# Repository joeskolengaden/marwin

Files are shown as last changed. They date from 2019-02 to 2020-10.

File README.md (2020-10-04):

# MARWIN
An Open Source Rapid Deployable DIY MARS Rover developed by Motify

## Primary Aim
To develop an opensource space rover by utilizing all posiible opensoure materals & resourses and also make the rover flexible  deployable for multiple purposes including research, resuce, military and defence purposes.

## Abstract

MARWIN is intended to be one of the first opensource DIY space rover projects which could be developed very easily. The rover is designed to be highly customizable with a modular design approach. MARWIN could open up the future for rapidly deployable rover solutions for exploration of other planets.

MARWIN intends to reduce the manufacturing cost and development time of rovers by implementing a quick and standardized design approach which could be customized very easily.

## Implementation Plan

* Rocker-Bogie system with RC.
* Scientific equipments ( sensor clusters).
* Power management system.
* Autonomous navigation.
* Video streaming and analysis.
* Testing and analysis.
* Modification and finalizing the design.

# Rover Actions Flowchart:



## For more details please check the WIKI page https://github.com/joeskolengaden/marwin/wiki

### Each folder in this MARWIN contains different areas of IoT projects, So this project can be splitted to different small scale projects, Enjoy MARWIN by Motify.in

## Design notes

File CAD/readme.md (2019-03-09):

This folder contains the Auto CAD files that is used for CNC cutting.

And in this file it includes the whole design of wheel of MARWIN.

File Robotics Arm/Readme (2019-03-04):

/*

NOTE: Four Servos of the Robotic Arm are connected to 4 PWM Pins of Arduino 

and these 4 servos are named a, b, c and d. 

If you want to control servo a, then type "90a/", 

where "90" is the PWM value (range is 0 - 255), 

"a" means servo a and "/" is string parse delimiter. 

Some other examples: 100a/ or 120b/ or 40c/ or 25d/

*/

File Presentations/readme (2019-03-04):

This folder contains the powerpoint presentations that we used for each reviews during the time of our project.

And each powerpoint presentation is uploaded here in the name of reviews.

Each powerpoints will have extremly minute changes in each slides so don't be much excited on each update on the powerpoints.

Final powerpoint will be uploaded on the time of our completion of project.

Enjoy the opensource DIY mars rover MARWIN by motify.in

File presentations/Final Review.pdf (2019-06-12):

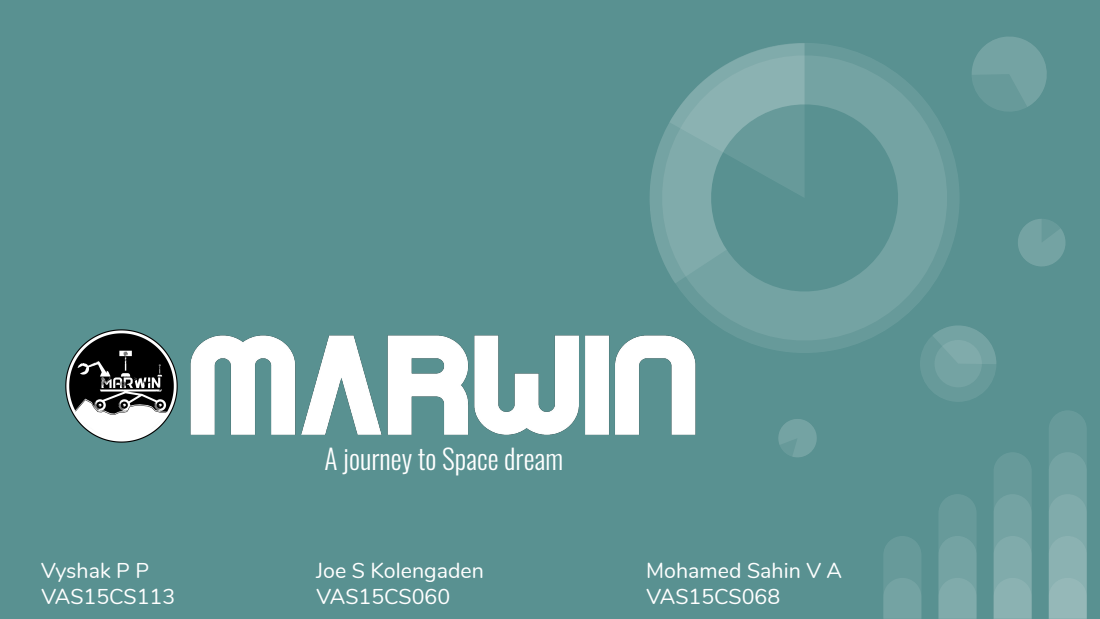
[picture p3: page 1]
Vyshak P P; Joe S Kolengaden; Mohamed Sahin V A; VAS15CS113; VAS15CS060; VAS15CS068

A journey to Space dream

# Contents

- Abstract
- Problem statement
- Methodologies
- Implementation Plan
- RoadMap
- Current progress
- Issues faced during prototyping
- Conclusion and Future scope

# Abstract

The basic aim behind the project is to address the need of open source projects in space industry. MARWIN is intended to be one of the first open source DIY space rover projects which could be developed very easily. The rover is designed to be highly customizable with a modular design approach. MARWIN could open up the future for rapidly deployable rover solutions for exploration of other planets. MARWIN intends to reduce the manufacturing cost and development time of rovers by implementing a quick and standardized design approach which could be customized very easily.

# Problem statement

To develop an open source space rover by utilizing all possible open source materials & resources and also make the rover flexible deployable for multiple purposes including research, rescue, military and defence purposes.

# Methodologies

- Architecture of MARWIN
- Rocker-Bogie Mechanism
- Sensor cluster
- Obstacle avoidance
- Obstacle detection
- Obstacle searching
- Rerouting
- Object detection
- WebApp

# Architecture of MARWIN

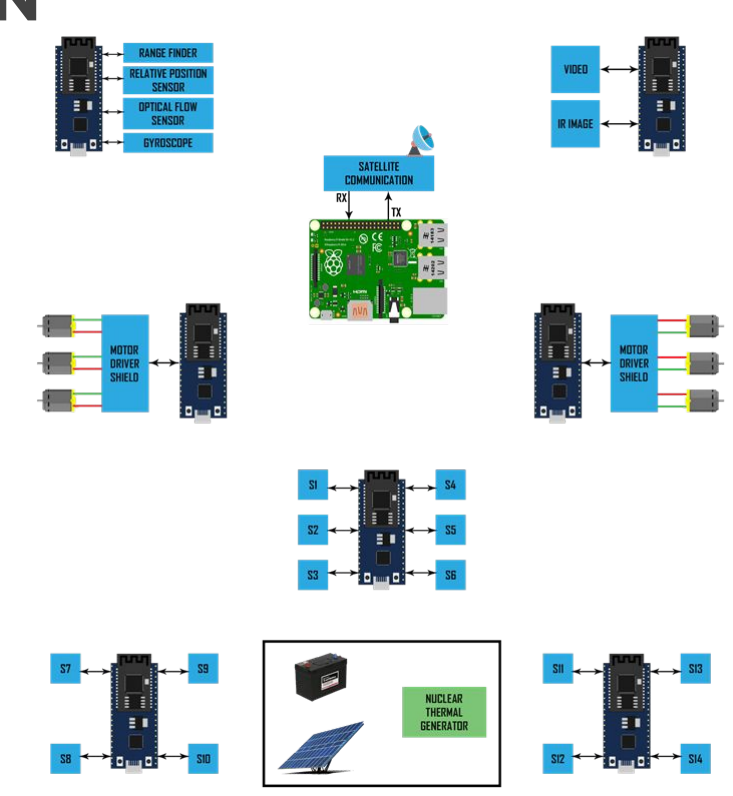
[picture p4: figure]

Modular designs are used in this architecture.

# Rocker-Bogie mechanism

- The ”rocker” part of the term comes from the rocking aspect of the larger, forward leg on each side of the suspension system. These rockers are connected to each other and the vehicle chassis through a differential.
- The ”bogie” part of the term refers to the smaller, rearward leg that pivots to the rocker in the middle and which has a drive wheel at each end.
- The rocker-bogie design has no springs or stub axles for each wheel, allowing the rover to climb over obstacles (such as rocks) that are up to twice the wheel’s diameter in size while keeping all six wheels on the ground.

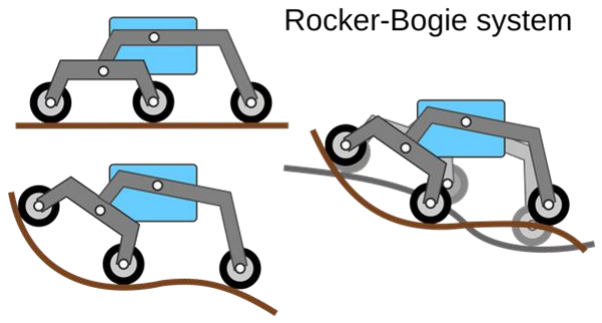
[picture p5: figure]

# Gas Sensor Cluster

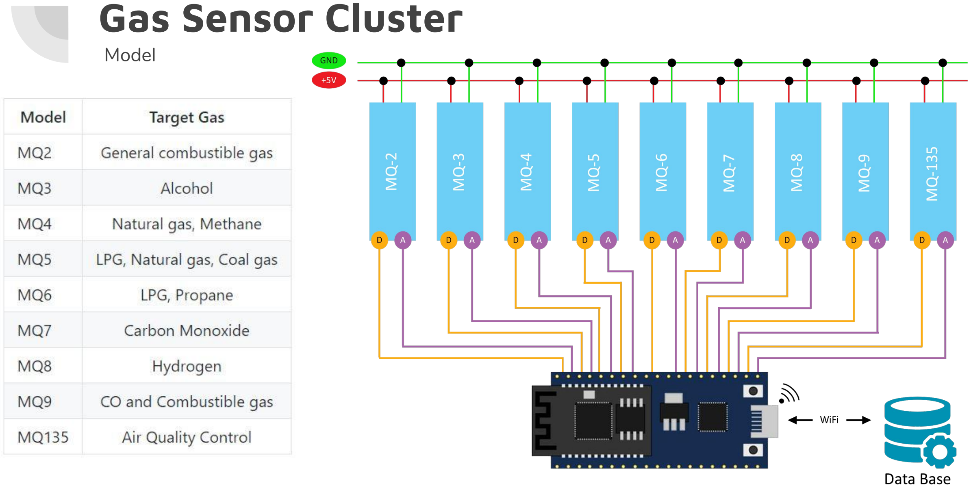
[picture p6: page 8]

Model

# Obstacle avoidance

Obstacle avoidance contains basic 3 algorithms namely,

- Obstacle detection
- Obstacle searching
- Rerouting

# Obstacle detection

Algorithm & FlowChart

1. Start

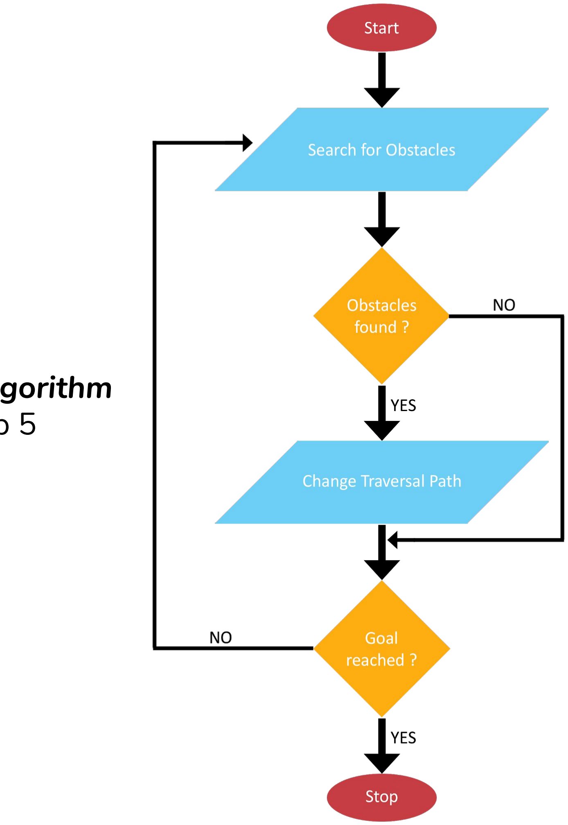
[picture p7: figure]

2. Search for obstacle using Obstacle Searching Algorithm
3. If found then change traversal path and goto step 5
4. Else goto step 5
5. Check whether goal is reached ?
6. If yes then goto step 8
7. Else goto step 2
8. Stop

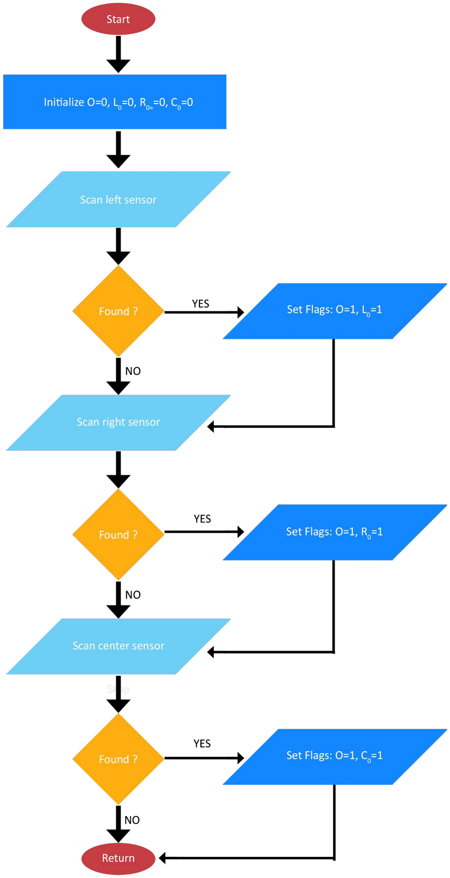
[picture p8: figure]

# Obstacle Searching

Algorithm & FlowChart

1. Start
2. Initialize flag variables O=0, Lo=0, Ro=0, Co=0
3. Scan Left sensor for obstacles.
4. If found then set flags O=1, Lo=1 and goto step 6
5. Else goto step 6
6. Scan Right sensor for obstacles.
7. If found then set flags O=1, Ro=1 and goto step 9
8. Else goto step 9
9. Scan Center sensor for obstacles.
10. If found then set flags O=1, Co=1 and goto step 12
11. Else goto step 12
12. Return to Obstacle Detection Algorithm with sensor values.

# Rerouting

Algorithm & FlowChart
1. Start

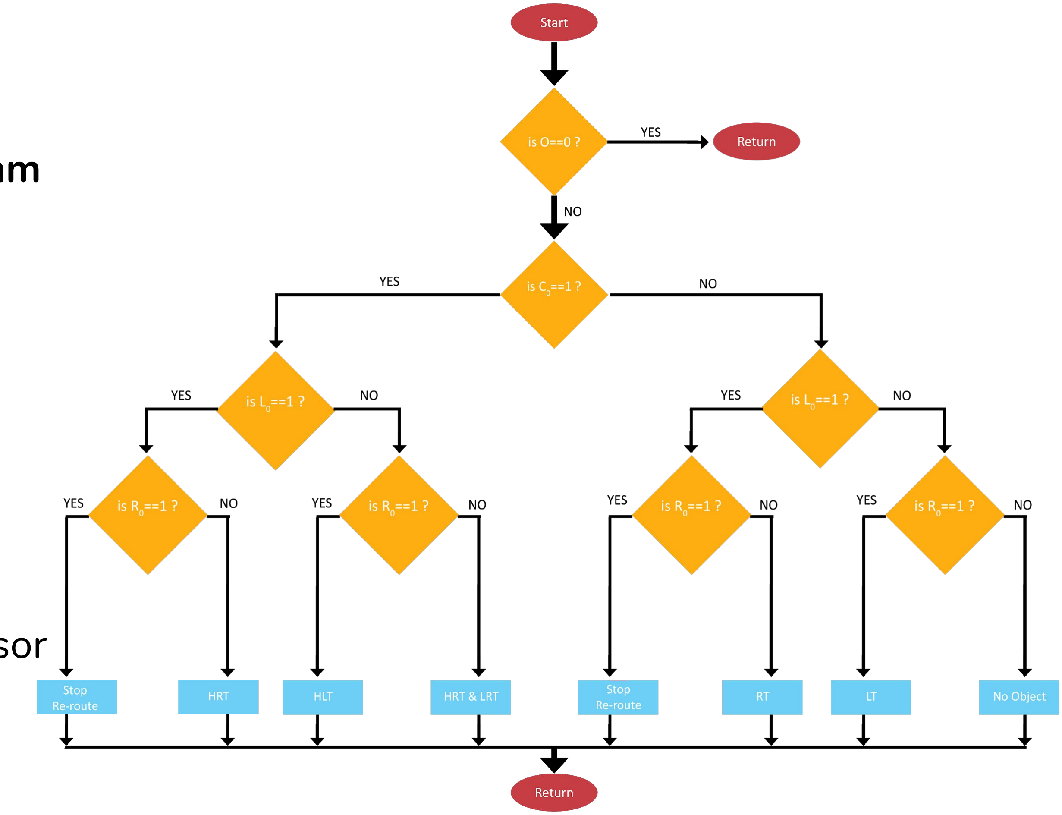
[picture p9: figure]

2. If O=0 then Return to Obstacle Detection Algorithm
3. Else do steps a to h
a. If Lo=1 & Ro=1 & Co=1 then stop & reroute
b. If Lo=1 & Ro=0 & Co=1 then HRT
c. If Lo=1 & Ro=0 & Co=0 then RT
d. If Lo=0 & Ro=1 & Co=1 then HLT
e. If Lo=0 & Ro=1 & Co=0 then LT
f. If Lo=0 & Ro=0 & Co=1 then HRT/HLT
g. If Lo=1 & Ro=1 & Co=0 then stop & reroute
h. If Lo=0 & Ro=0 & Co=0 then No Obstacles
4. Return to Obstacle Detection Algorithm with sensor values.

# Rerouting

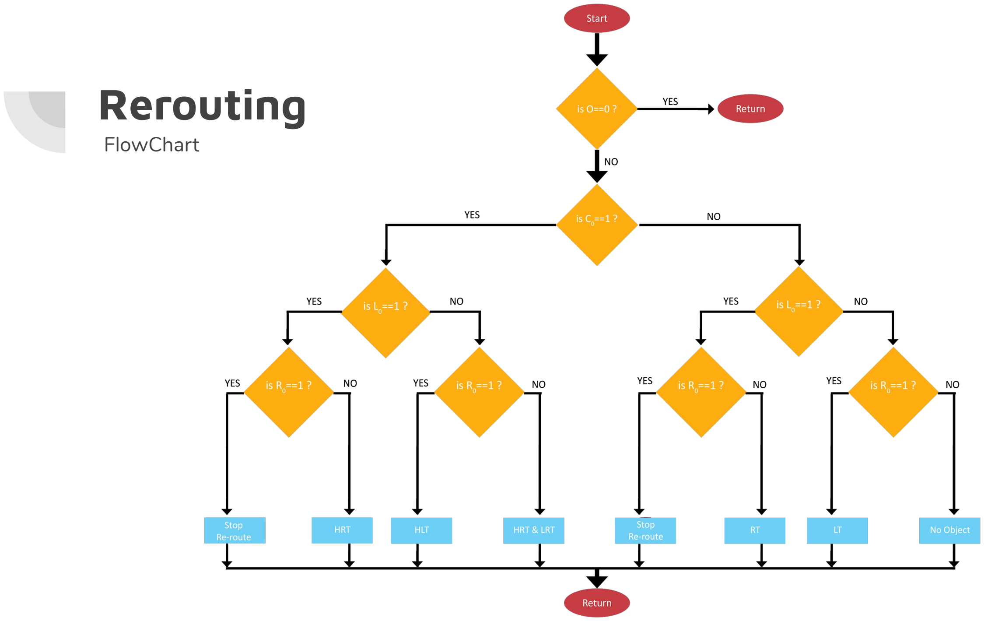
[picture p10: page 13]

FlowChart

# Object detection

Prior detection systems repurpose classifiers or localizers to perform detection. They applythemodeltoanimageatmultiplelocationsandscales. Highscoringregionsofthe image are considered detections.

Here we used TensorFlow for object detection.

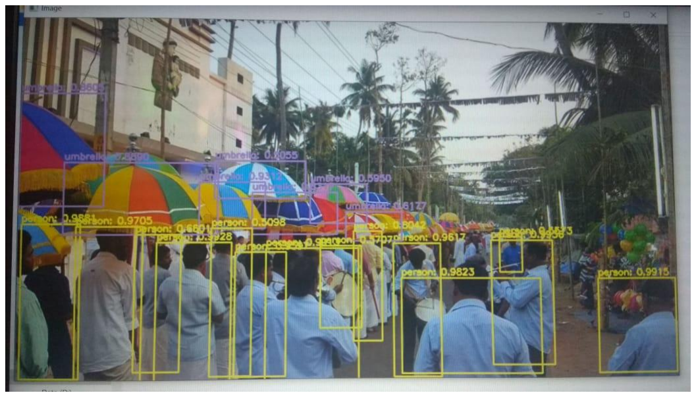
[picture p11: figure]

# Working

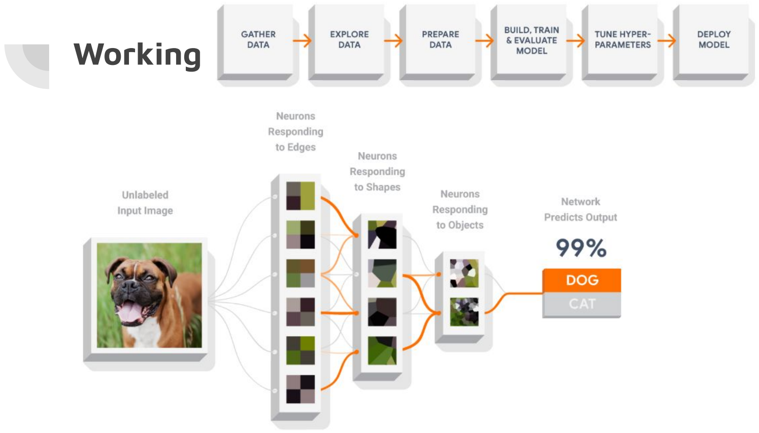
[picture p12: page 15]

# WebApp

A web application is a computer program that utilizes web browsers and web technology to perform tasks over the Internet.

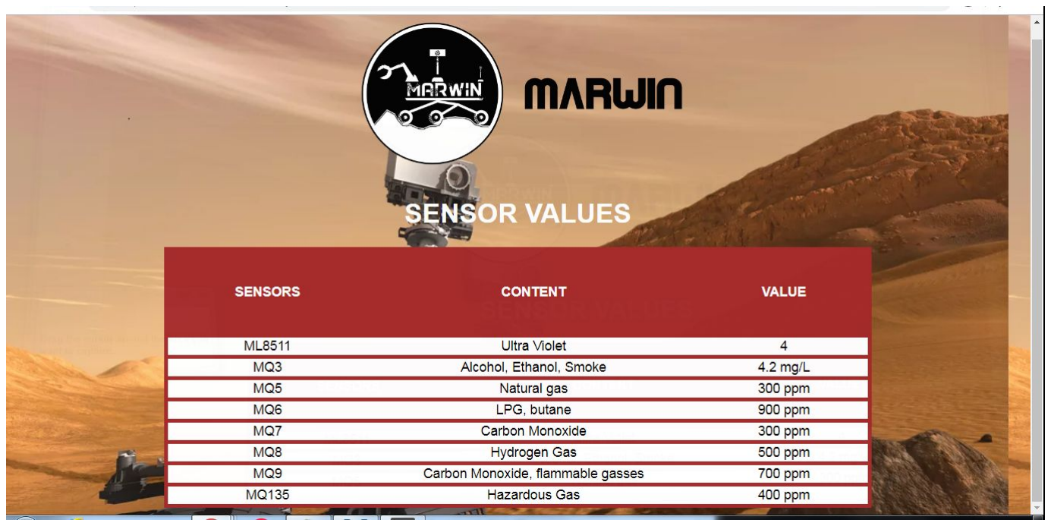
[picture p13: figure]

Our web app is created using:

- Flask : Python Based mini-Web Framework
- MongoDB : Database Server
- Pymongo : Database Connector
- HTML : For webpage

# Implementation Plan

- Rocker-Bogie system.
- Scientific equipments (sensor clusters).
- Power management system.
- Autonomous navigation.
- Video streaming and analysis.
- Testing and analysis.
- Modification and finalizing the design

# RoadMap

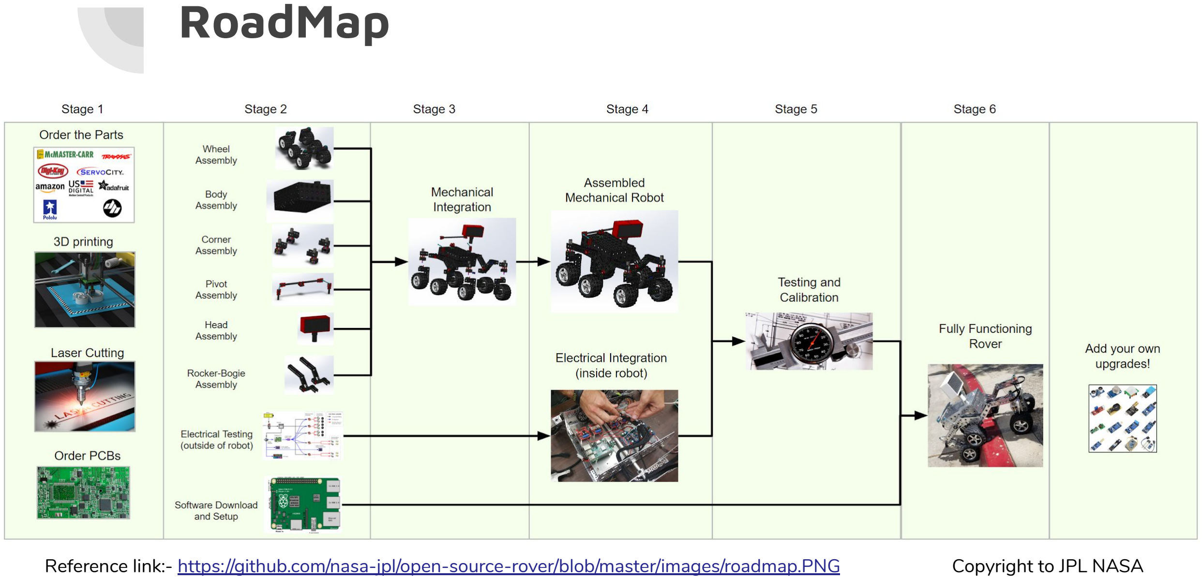
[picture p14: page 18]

Reference link:- https://github.com/nasa-jpl/open-source-rover/blob/master/images/roadmap.PNG | Copyright to JPL NASA

# Current Progress

- | Rocker-Bogie Mechanism | Designed
- | Object Detection | On developing
- | Gas Sensor Cluster | Developing cluster
- | Wheel Assembly | Implemented
- | WebApp | On developing
- | Navigation System | On developing

# Current Progress

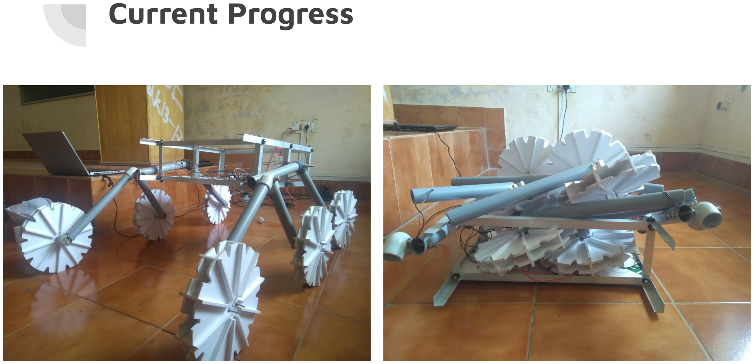
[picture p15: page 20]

# Current Progress

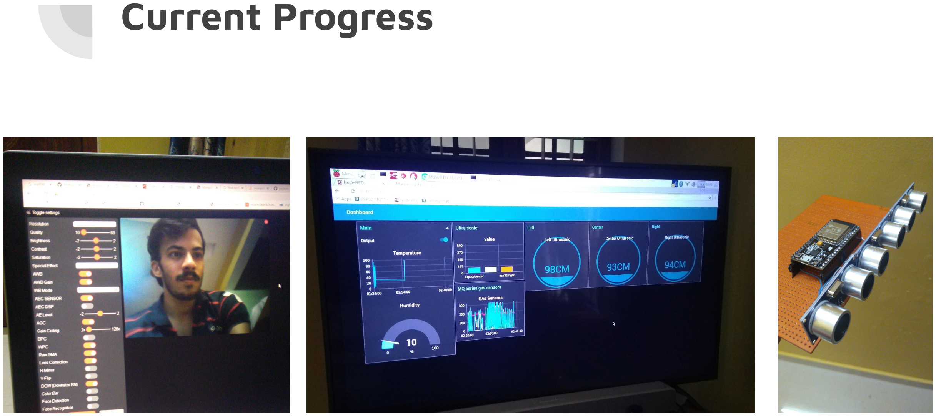
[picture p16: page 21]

# Issues Faced

- Rocker-Bogie Mechanism
- Wheel Assembly
- Sensor Clustering
- Response Time
- LIVE Object Recognition
- Robotic Arm
- Power Source
- Cost

# Conclusion and Future scope

As a team we achieved far more in a short timespan. The journey through the developing and integrating part of this project was a great one. In the present situation there are a high amount disasters happening unexpectedly also different kinds of situations are rising where the human kinds are not reachable. So we are expecting our space rover based marwin could also implement in such situations and can obtain a positive result. In future we will be able to implement the present prototype on the basis of the needs. That can be based on the situations. By improving we can make this rover more user friendly by also including machine learning concept to it. This makes the rover to learn the ongoing datas and can act as a highly AI based robot which will be completely autonomous and the human efforts decreases.

# Note

Choose the right materials and good quality electronics for making electro-mechanical projects

# GITHub

Open sourced every bit of code via Github.com

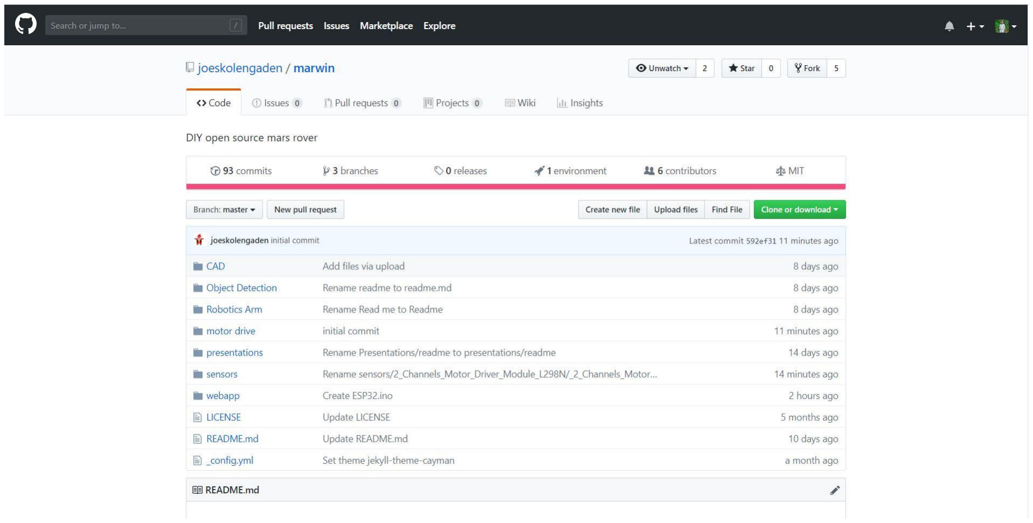
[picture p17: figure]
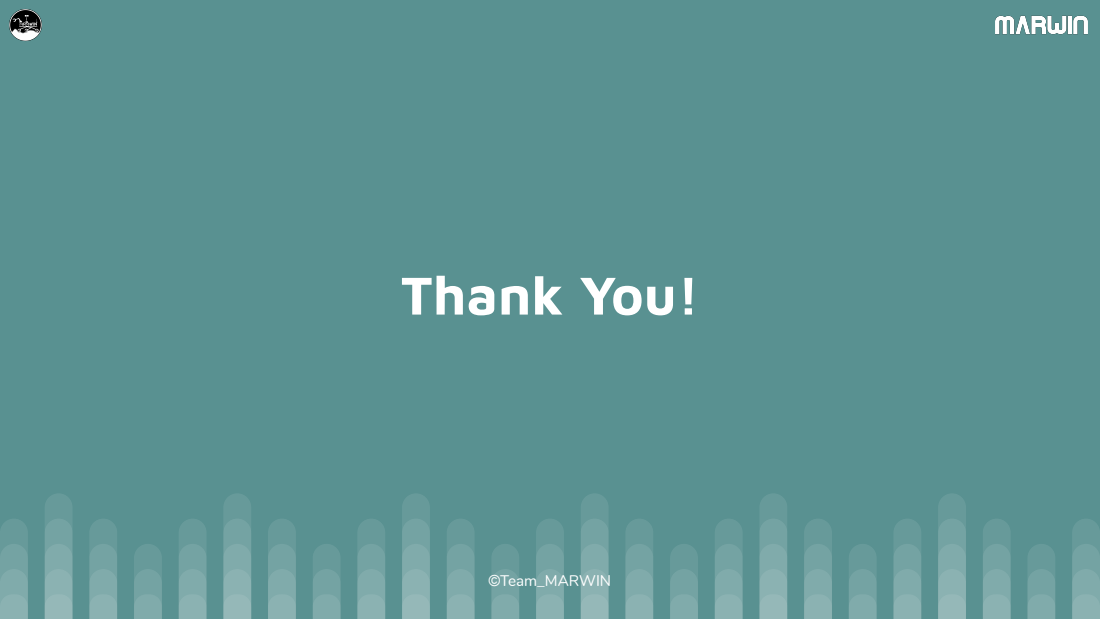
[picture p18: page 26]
Thank You!; ©Team_MARWIN

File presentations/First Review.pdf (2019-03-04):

## An Open Source Rapid Deployable DIY MARS Rover

# MARWIN

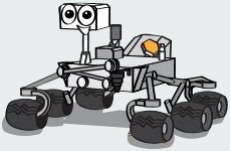
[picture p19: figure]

Team Members

Vyshak P P (VAS15CS113)

Mohamed Sahin V A (VAS15CS068)

Joe S Kolengaden (VAS15CS060)

Group A2

# Contents

## - Abstract - Problem Statement - Design - Implementation Plan

# Introduction

- Ever growing demand and developments in space exploration industry have inspired us to create MARWIN.
- Rapid industrialization and entry of private firms in space industry have opened up new possibilities for startups.

# Abstract: project background

- The basic aim behind the project is to address the need of open source projects in space industry.
- The MARWIN rover is designed to be modular and customizable according to various explorational needs.
- The basic use of MARWIN will be to avail rapid deployable rover solutions in human exploration of other planets.

# Problem statement:

- The working of space rover cannot be exhibited to the public directly and it is because of high maintenance costs.
- There is a lack of open-source projects that support space exploration and related technology.
- There is no available prototype or even design for rapid deployable modular rovers.

# Design

- The design principle of MARWIN is logically divided into 3*3*3 like Rubik’s Cube design approach.
- We use Rocker Bogie mechanism for traversing through rough terrain.
- We provide any of the scientific equipment in this prototype.
- Atmospheric content Sensor : Which enables us to detect the presence of different types of Gases.
- Life detecting robotic system : Which detects the presence of biological life form.

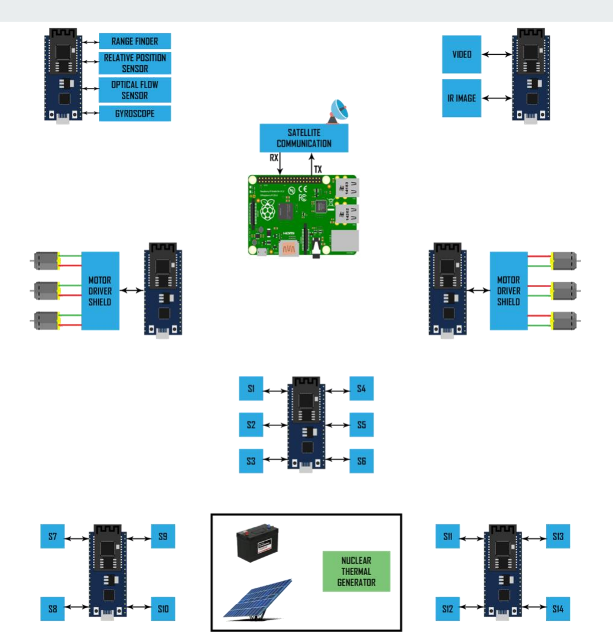
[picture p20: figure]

# Architecture

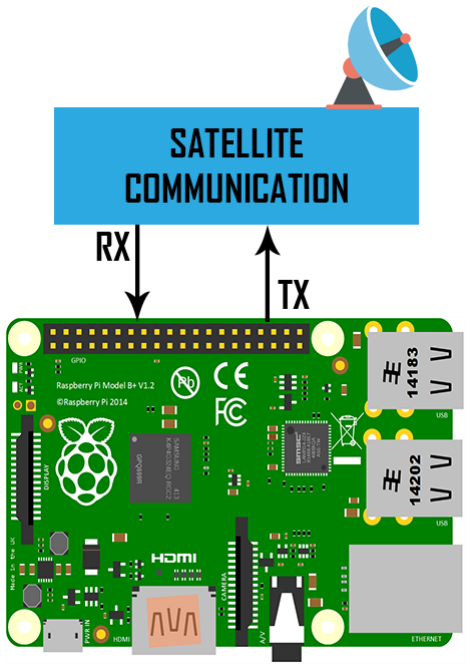
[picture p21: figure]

# Raspberry Pi 3 B+

- It acts as the brain (Motherboard).
- Buffers all data in the internal server (Database).

# Live Analysis

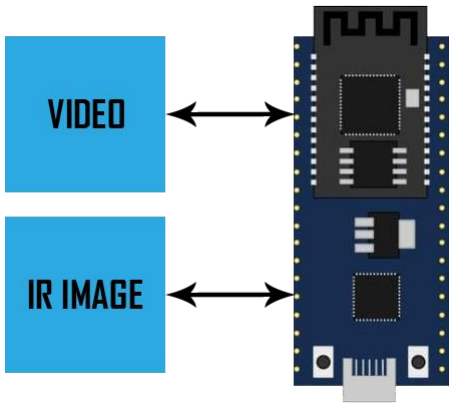
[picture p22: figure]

# Navigation Block

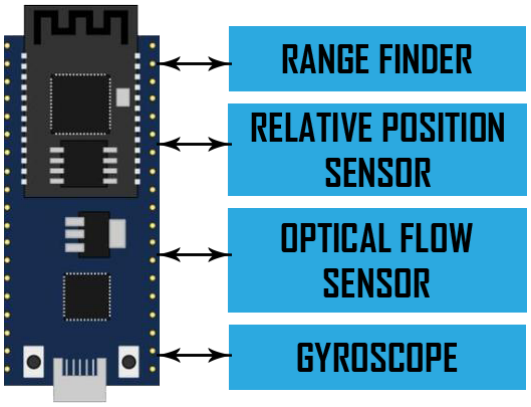
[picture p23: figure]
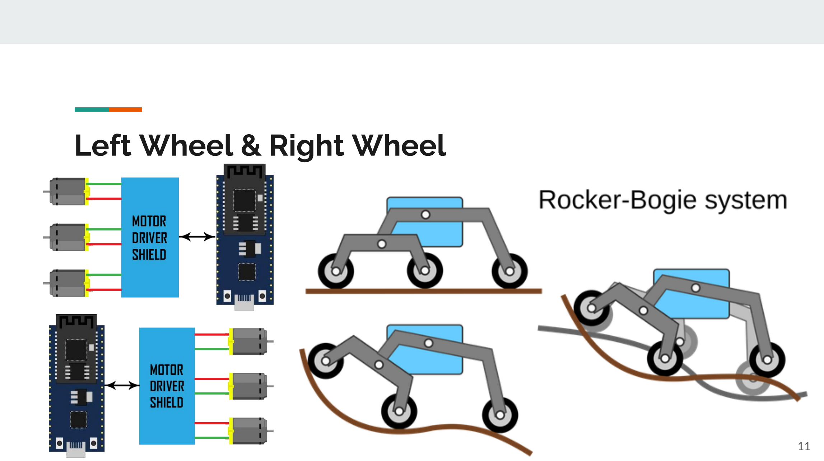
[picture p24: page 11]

# Left Wheel & Right Wheel

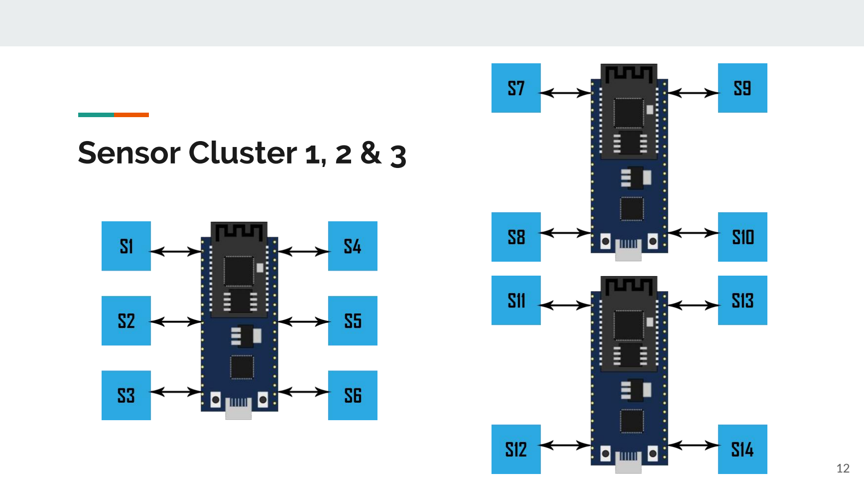
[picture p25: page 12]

# Sensor Cluster 1, 2 & 3

# Power management block

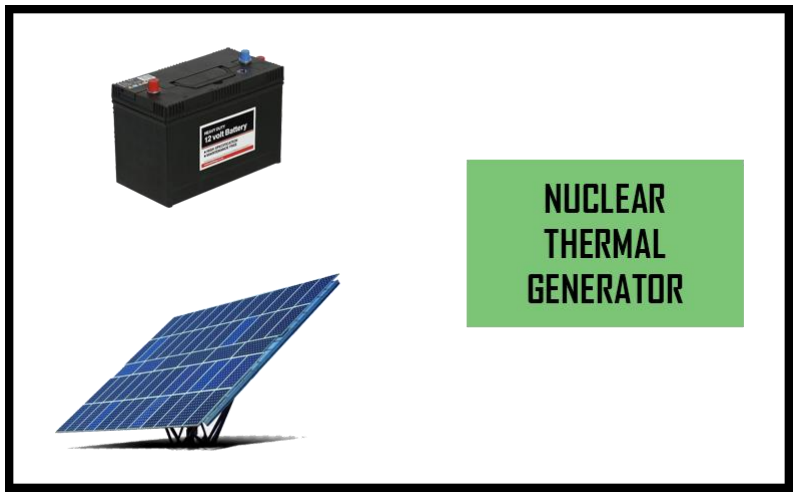
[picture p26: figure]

# Implementation Plan

1. Rocker-Bogie system with RC .
2. Scientific equipments ( sensor clusters).
3. Power management system.
4. Autonomous navigation.
5. Video streaming and analysis.
6. Testing and analysis.
7. Modification and finalizing the design.

Note: All the project work will be made open source via GitHub.


# Goal Based Navigation


# Rover Actions Flowchart


# Why ESP32 ?

# ESP32 dual core


- Each core can do different task independently.
- Sync can be achieved via Mutually Exclusive Semaphores.
- The 32bit dual core clocked at 180Mhz can outperform AtMEga328p( Arduino UNO R3) by

# Sensor list

- MQ-2 - Methane, Butane, LPG, smoke
- MQ-3 - Alcohol, Ethanol, smoke
- MQ-4 - Methane, CNG Gas
- MQ-5 - Natural gas, LPG
- MQ-6 - LPG, butane gas
- MQ-7 - Carbon Monoxide
- MQ-8 - Hydrogen Gas
- MQ-9 - Carbon Monoxide, flammable gasses
- MLX90614 - IR temperature sensor
- MAG3110 - Magnetometer
- | ITG 3200 | - Gyroscope
- ADXL 345 - Accelorometer
- | TSL 102 | - Luminosity sensor
- | ML8511 | - UV detector
- | BMP180 | - Barometric Pressure/altitude sensor
- MMA84551 - Inclination sensor

# Literature survey

- Terrain feature extraction and assessment.

## - Terrain-Based Navigation - Obstacle-Avoidance Navigation - Goal-Based Navigation - Behavior Integration

Paper: An Intelligent Terrain-Based Navigation System for Planetary Rovers

# Literature survey (cont….)

- Wheel supporting system.

## - Wheel defect detection

- Wavelet-SVM
- Deep Learning

Paper: Wheel defect detection using machine learning.

# Literature survey (cont….)

- Prototype for searching signs of life in mars.
- Laser and reflectometer tech to detect traces of methane.
- Surveying and localization of data.

Paper: Robot System to Search for Signs of Life on Mars

Applications…..

Highly modified versions of the rover can be used in fields such as

1. Defence .
2. Rescue operations.
3. Disaster management.
4. Remote sensing.
5. Agriculture.
6. R&D.

And more...

# Thank you !!


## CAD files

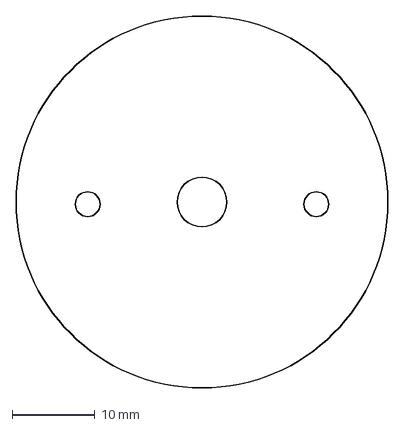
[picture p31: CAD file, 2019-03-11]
CAD/Wheel Assembly/CNC/filler.dxf
45.0 x 45.0 mm

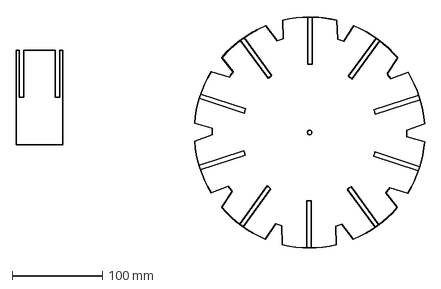
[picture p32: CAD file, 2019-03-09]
CAD/Wheel Assembly/CNC/wheel.dxf
452.9 x 258.4 mm

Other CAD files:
CAD/Wheel Assembly/CNC/filler.dwg
CAD/Wheel Assembly/CNC/wheel.dwg

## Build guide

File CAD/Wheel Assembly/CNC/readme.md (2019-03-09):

This folder contains the Auto CAD files that is used for CNC cutting.

And in this file it includes the whole design of wheel of MARWIN.

Wheel Diameter = 256 mm

Center Hole = 6 mm

Slits = 5 mm

No. of spokes = 10

Inner Clamp diameter = 51.2 mm

Inner Clamp Center hole = 6 mm

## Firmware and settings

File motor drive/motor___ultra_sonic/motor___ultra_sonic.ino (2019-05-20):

#include <WiFi.h>
#include <PubSubClient.h>
#include <Wire.h>

/*
#include "BluetoothSerial.h"

#if !defined(CONFIG_BT_ENABLED) || !defined(CONFIG_BLUEDROID_ENABLED)
#error Bluetooth is not enabled! Please run `make menuconfig` to and enable it
#endif

BluetoothSerial SerialBT;
*/

// Replace the next variables with your SSID/Password combination
 char* ssid ="motify_one";
 char* password ="trigon2016";

// Add your MQTT Broker IP address, example:
//const char* mqtt_server = "192.168.1.144";
const char* mqtt_server = "192.168.43.236";

WiFiClient espClient;
PubSubClient client(espClient);
long lastMsg = 0;
char msg[50];
int value = 0;

float left = 0;
float center = 0;
float right = 0;


int trigPin1=2;
int echoPin1=4;

int trigPin2=16;
int echoPin2=17;

int trigPin3=5;
int echoPin3=18;




//L293D
//Motor L1
const int motorPin1  = 27;  // Pin 14 of L293
const int motorPin2  = 26;  // Pin 10 of L293
int enable1Pin = 14;

//Motor R1
const int motorPin3  = 32; // Pin  7 of L293
const int motorPin4  = 33;  // Pin  2 of L293
int enable2Pin = 25;

// Setting PWM properties
const int freq = 30000;
const int pwmChannel = 0;
const int resolution = 8;
int dutyCycle = 250;





void setup() {
  Serial.begin(115200);
  
//  SerialBT.begin("ESP32test"); //Bluetooth device name
//  Serial.println("The device started, now you can pair it with bluetooth!");
     
     
     setup_wifi();
  client.setServer(mqtt_server, 1883);
  client.setCallback(callback);


  pinMode(trigPin1, OUTPUT);
  pinMode(echoPin1, INPUT);
   pinMode(trigPin2, OUTPUT);
  pinMode(echoPin2, INPUT);
   pinMode(trigPin3, OUTPUT);
  pinMode(echoPin3, INPUT);
   
    //Set pins as outputs
    pinMode(motorPin1, OUTPUT);
    pinMode(motorPin2, OUTPUT);
    pinMode(motorPin3, OUTPUT);
    pinMode(motorPin4, OUTPUT);
    
    pinMode(enable1Pin, OUTPUT);
    pinMode(enable2Pin, OUTPUT);

    // configure LED PWM functionalitites
  ledcSetup(pwmChannel, freq, resolution);
  
  // attach the channel to the GPIO to be controlled
  ledcAttachPin(enable1Pin, pwmChannel);
  ledcAttachPin(enable2Pin, pwmChannel);


}






void setup_wifi() {
  delay(10);
  // We start by connecting to a WiFi network
  Serial.println();
  Serial.print("Connecting to ");
  Serial.println(ssid);

  WiFi.begin(ssid, password);

  while (WiFi.status() != WL_CONNECTED) {
    delay(500);
    Serial.print(".");
  }

  Serial.println("");
  Serial.println("WiFi connected");
  Serial.println("IP address: ");
  Serial.println(WiFi.localIP());
}


void callback(char* topic, byte* message, unsigned int length) {
  Serial.print("Message arrived on topic: ");
  Serial.print(topic);
  Serial.print(". Message: ");
  String messageTemp;
  
  for (int i = 0; i < length; i++) {
    Serial.print((char)message[i]);
    messageTemp += (char)message[i];
  }
  Serial.println();

  // Feel free to add more if statements to control more GPIOs with MQTT

  // If a message is received on the topic esp32/output, you check if the message is either "on" or "off". 
  // Changes the output state according to the message
  if (String(topic) == "esp32/output") {
    Serial.print("Changing output to ");
    if(messageTemp == "on"){
      Serial.println("on");
      //digitalWrite(ledPin, HIGH);
    }
    else if(messageTemp == "off"){
      Serial.println("off");
      //digitalWrite(ledPin, LOW);
    }
  }
}

void reconnect() {
  // Loop until we're reconnected
  while (!client.connected()) {
    Serial.print("Attempting MQTT connection...");
    // Attempt to connect
    if (client.connect("ESP8266Client")) {
      Serial.println("connected");
      // Subscribe
      client.subscribe("esp32/output");
    } else {
      Serial.print("failed, rc=");
      Serial.print(client.state());
      Serial.println(" try again in 5 seconds");
      // Wait 5 seconds before retrying
      delay(5000);
    }
  }
}





void loop() {


 if (!client.connected()) {
    reconnect();
  }
  client.loop();

  
   long now = millis();
  if (now - lastMsg > 5000) {
    lastMsg = now;
    
  
  long duration1, distance1;
  digitalWrite(trigPin1, LOW);  // Added this line
  delayMicroseconds(2); // Added this line
  digitalWrite(trigPin1, HIGH);
  delayMicroseconds(10); // Added this line
  digitalWrite(trigPin1, LOW);
  duration1 = pulseIn(echoPin1, HIGH);
  distance1 = (duration1/2) / 29.1;
  
  
   if (distance1 >= 500 || distance1 <= 0){
    Serial.println("Out of range");
    right=distance1;
  }
  else {
    Serial.print ( "Sensor1  ");
    Serial.print ( distance1);
    Serial.println("cm");
    right=distance1;
    
  }
 //delay(200);
  
long duration2, distance2;
  digitalWrite(trigPin2, LOW);  // Added this line
  delayMicroseconds(2); // Added this line
  digitalWrite(trigPin2, HIGH);
  delayMicroseconds(10); // Added this line
  digitalWrite(trigPin2, LOW);
  duration2 = pulseIn(echoPin2, HIGH);
  distance2= (duration2/2) / 29.1;
  
  
   if (distance2 >= 500 || distance2 <= 0){
    Serial.println("Out of range");
    center=distance2;
  }
  else {
    Serial.print("Sensor2  ");
    Serial.print(distance2);
    Serial.println("cm");
    center=distance2;
    
  }
  //delay(200);
  
  long duration3, distance3;
  digitalWrite(trigPin3, LOW);  // Added this line
  delayMicroseconds(2); // Added this line
  digitalWrite(trigPin3, HIGH);
  delayMicroseconds(10); // Added this line
  digitalWrite(trigPin3, LOW);
  duration3 = pulseIn(echoPin3, HIGH);
  distance3= (duration3/2) / 29.1;

   if (distance3 >= 500 || distance3 <= 0){
    Serial.println("Out of range");
    left=distance3;
  }
  else {
    Serial.print("Sensor3  ");
    Serial.print(distance3);
    Serial.println("cm");
    left=distance3;
    
  }
  //delay(200);


                                                           //MOTOR DEIVER 
   if((right>75)&&(center>75)&&(left>75))
   {
   
    //This code will turn Motor forwards
    Serial.println("Going froward");
    
    digitalWrite(motorPin1, HIGH);
    digitalWrite(motorPin2, LOW);
    digitalWrite(motorPin3, LOW);
    digitalWrite(motorPin4, HIGH);
    }
    
    else if((right<25)&(center<25)&(left>75)){
    //this code will turn rover right
    Serial.println("Turning right");

    digitalWrite(motorPin1, LOW);
    digitalWrite(motorPin2, HIGH);
    digitalWrite(motorPin3, LOW);
    digitalWrite(motorPin4, HIGH);
    //ledcWrite(pwmChannel, dutyCycle);
    //ledcWrite(pwmChannel, dutyCycle);
   }

       else if((right>75)&(center<25)&(left<25)){
    //this code will turn rover left
    Serial.println("Turning left");

    digitalWrite(motorPin1, HIGH);
    digitalWrite(motorPin2, LOW);
    digitalWrite(motorPin3, HIGH);
    digitalWrite(motorPin4, LOW);
    //ledcWrite(pwmChannel, dutyCycle);
    //ledcWrite(pwmChannel, dutyCycle);
   }
     else if((right<25)&(center<25)&(left<25)){
    //this code will turn rover backwards
    Serial.println("Going reverse");

    digitalWrite(motorPin1, LOW);
    digitalWrite(motorPin2, HIGH);
    digitalWrite(motorPin3, HIGH);
    digitalWrite(motorPin4, LOW);
    //ledcWrite(pwmChannel, dutyCycle);
    //ledcWrite(pwmChannel, dutyCycle);
   }
   
   else if((right<75)||(center<75)||(left<75))
   {
    //this code will stop the rover 
    Serial.println("Stop");
    digitalWrite(motorPin1, LOW);
    digitalWrite(motorPin2, LOW);
    digitalWrite(motorPin3, LOW);
    digitalWrite(motorPin4, LOW);
    }

    ledcWrite(pwmChannel, dutyCycle);

    
  
  char leftString[8];
  char centerString[8];
  char rightString[8];

  dtostrf(left, 1, 2, leftString);
  dtostrf(center, 1, 2, centerString);
  dtostrf(right, 1, 2, rightString);
  
  client.publish("esp32_1/left", leftString);
  client.publish("esp32_1/center", centerString);
  client.publish("esp32_1/right", rightString);
  

  

}
}

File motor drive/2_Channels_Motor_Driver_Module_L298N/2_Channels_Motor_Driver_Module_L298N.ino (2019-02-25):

/************************************************
Editor   : MYBOTIC www.mybotic.com.my
Date     : 29 Aug 2014
Project  : 2 Channels Motor Driver Module
*************************************************/

//define motor 1 related pins
#define IN1 9
#define IN2 8
#define ENA 10

//define motor 2 related pins
#define IN3 7
#define IN4 6
#define ENB 5

void setup()
{ 
  //set output for motor 1 related pins
  pinMode(IN1, OUTPUT);
  pinMode(IN2, OUTPUT);
  pinMode(ENA, OUTPUT);
  
  //set output for motor 2 related pins
  pinMode(IN3, OUTPUT);
  pinMode(IN4, OUTPUT);
  pinMode(ENB, OUTPUT);
  
  //set motor 1 run in clockwise
  digitalWrite(IN1, HIGH);
  digitalWrite(IN2, LOW);
  
  //set motor 2 run in anticlockwise
  digitalWrite(IN3, HIGH);
  digitalWrite(IN4, LOW);
}

void loop()
{
  int PWM_Value = 0; //PWM value for motor 1 and 2
  
  //Motor 1 and Motor 2 run with gradually increasing speed until Max
  for(PWM_Value = 0; PWM_Value<=255; PWM_Value+=5)
  {
    analogWrite(ENA, PWM_Value); //set PWM to Motor 1
    analogWrite(ENB, PWM_Value); //set PWM to Motor 2
    delay(100);
  }
  
  //Motor 1 and Motor 2 run with gradually descreasing speed until Stop
  for(PWM_Value = 255; PWM_Value>=0; PWM_Value-=5)
  {
    analogWrite(ENA, PWM_Value); //set PWM to Motor 1
    analogWrite(ENB, PWM_Value); //set PWM to Motor 2
    delay(100);
  }
}

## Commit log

2019-02-16 MQ Series Gas Sensors
    initial test codes
2019-02-22 Rename mq series/mq_2/mq_2.ino to sensors/mq series/mq_2/mq_2.ino
2019-02-22 Rename mq series/mq_3/mq_3.ino to sensors/mq series/mq_3/mq_3.ino
2019-02-22 Rename mq series/mq_4/mq_4.ino to sensors/mq series/mq_4/mq_4.ino
2019-02-22 Rename mq series/mq_5/mq_5.ino to sensors/mq series/mq_5/mq_5.ino
2019-02-22 Rename mq series/mq_5_r0_test/mq_5_r0_test.ino to sensors/mq series/mq_5_r0_test/mq_5_r0_test.ino
2019-02-22 Rename mq series/mq_series_sensors_combined/mq_series_sensors_combined.ino to sensors/mq series/mq_series_sensors_combined/mq_series_sensors_combined.ino
2019-02-25 L298N motor driver code
2019-03-19 Rename sensors/2_Channels_Motor_Driver_Module_L298N/_2_Channels_Motor_Driver_Module_L298N.ino to motor drive/2_Channels_Motor_Driver_Module_L298N/2_Channels_Motor_Driver_Module_L298N.ino
2019-05-06 esp32 cam arduino code
2019-05-06 Rename CameraWebServer.ino to esp32 cam arduino/CameraWebServer.ino
2019-05-06 Rename camera_pins.h to esp32 cam arduino/camera_pins.h
2019-05-06 Rename app_httpd.cpp to esp32 cam arduino/app_httpd.cpp
2019-05-06 Rename camera_index.h to esp32 cam arduino/camera_index.h
2019-05-06 Create 3 ultra sonic mqtt
    range from 3 ultrasonic sensors are collected and passed through MQTT server
2019-05-07 Ai camera
2019-05-20 motor drive with ultra sonic and mqtt updates
